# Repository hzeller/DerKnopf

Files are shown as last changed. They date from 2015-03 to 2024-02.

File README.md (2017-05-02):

Remote controlled volume knob
=============================

_**Knopf, der** German: button, knob (Pronounciation: /knɔpf/)_

A project to upgrade an amplifier volume knob from a simple regular
potentiometer to a digital one that still can be controlled
directly at the amplifier but also via an infrared remote control.

Replaces the regular potentiometer with a [DS1882] and a rotational encoder.
Visual feedback with a charlie-plexed LED ring.

The interesting part is the infrared remote control: another rotational encoder,
with an infrared transmitter: a wireless extension of the volume knob.

The rotational encoders have a secondary push-button function which is used to
enable muting. Another press on that button will un-mute and go back to the
original volume.

# Remote control sender
The [sender](./pcb/remote-control) is a 20mm round PCB and thus roughly the
size of the volume knob and the diameter of a CR2032 battery.

Provides a rotational encoder with an integrated button (used for 'mute'), two
Infrared LEDs to send.
Microcontroller: Attiny44. Quiescent current: < 0.2 μA. Runs on CR2032.

Top                    | Side                       | Bottom
-----------------------|----------------------------|--------------------------
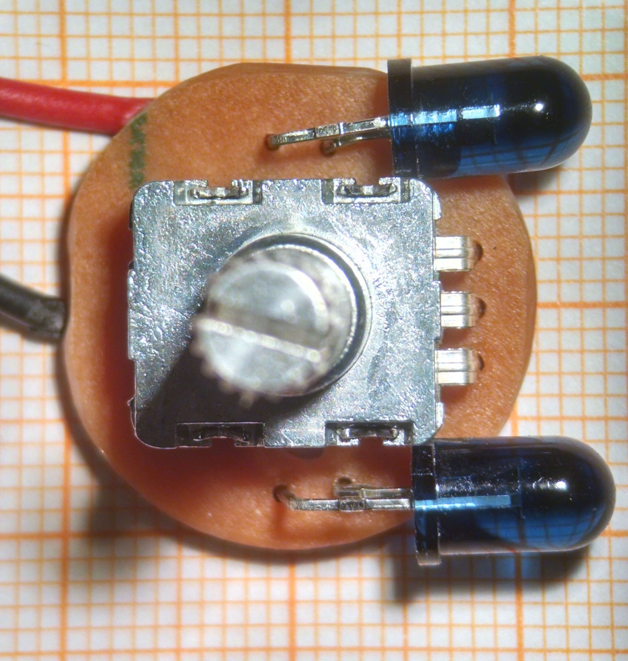
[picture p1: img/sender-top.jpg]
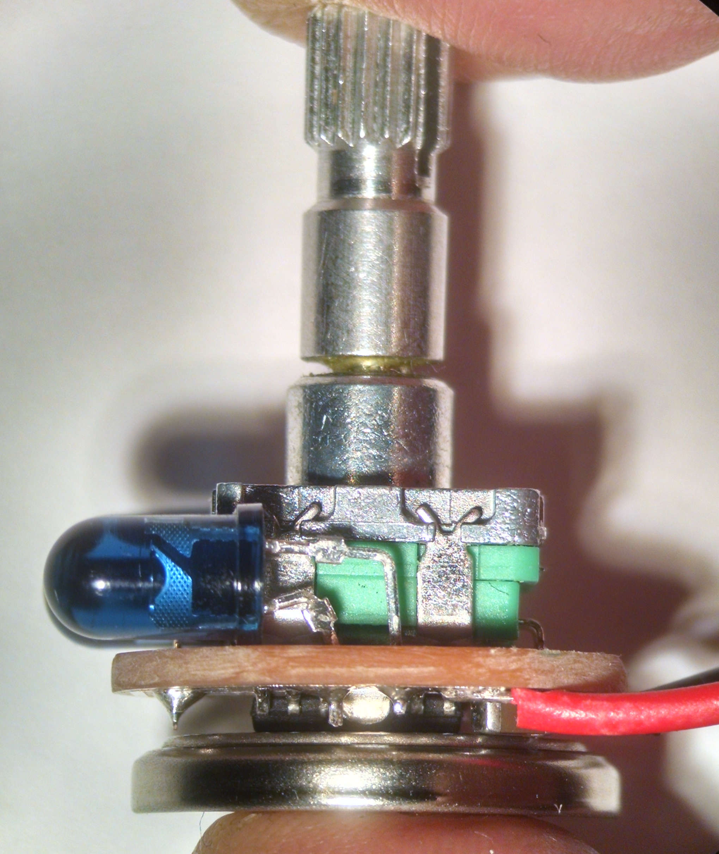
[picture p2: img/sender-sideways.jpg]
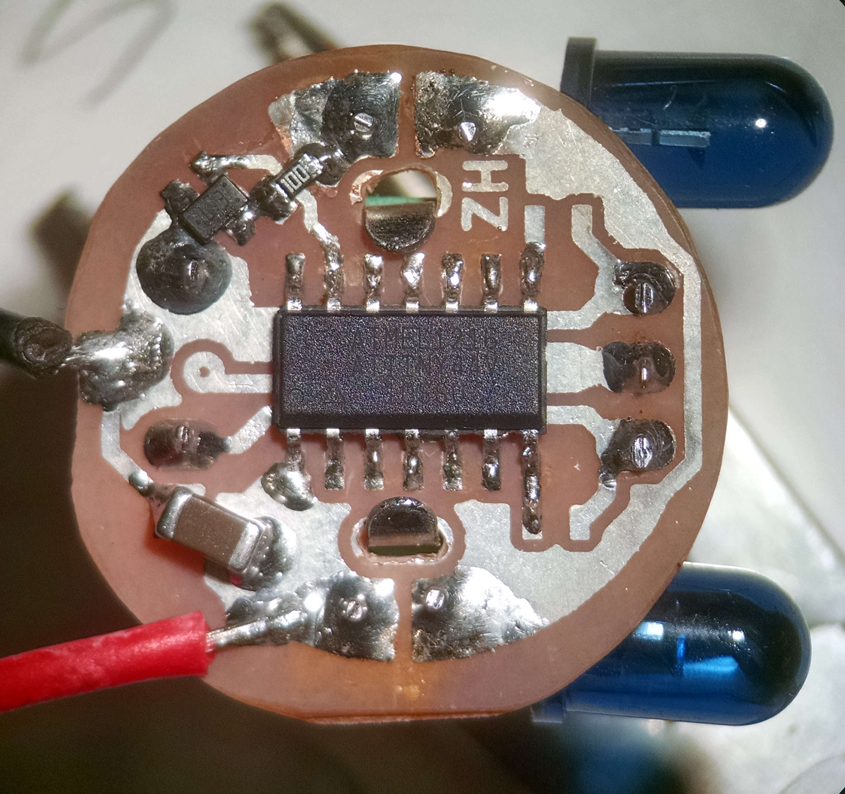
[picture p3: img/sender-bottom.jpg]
||

TODO: build acryilic housing.

Code in [sender/](./sender) directory.

# DigiPot Receiver

The [receiver](pcb/digi-pot) behaves like a logarithmic stereo potentiomter.
It takes an input signal from a local rotational encoder or the infrared
signal (amplified and prepared with a Vishay TSOP75338).
It provides two 'potentiometer' outputs. The local encoder has a 32 step/turn
resolution of which 30 are used (to have a visual 'gap' between min and max
like in a regular pot).

Microcontroller: Attiny48.
Runs on +5V (digital processing) and +/-6V (Analog). For these voltge rails,
there is a little separate [power supply PCB](./pcb/power)

Code in [receiver/](./receiver) directory.

Render                      |  Bottom                      | Shallow side view
----------------------------|------------------------------|----------------------------|
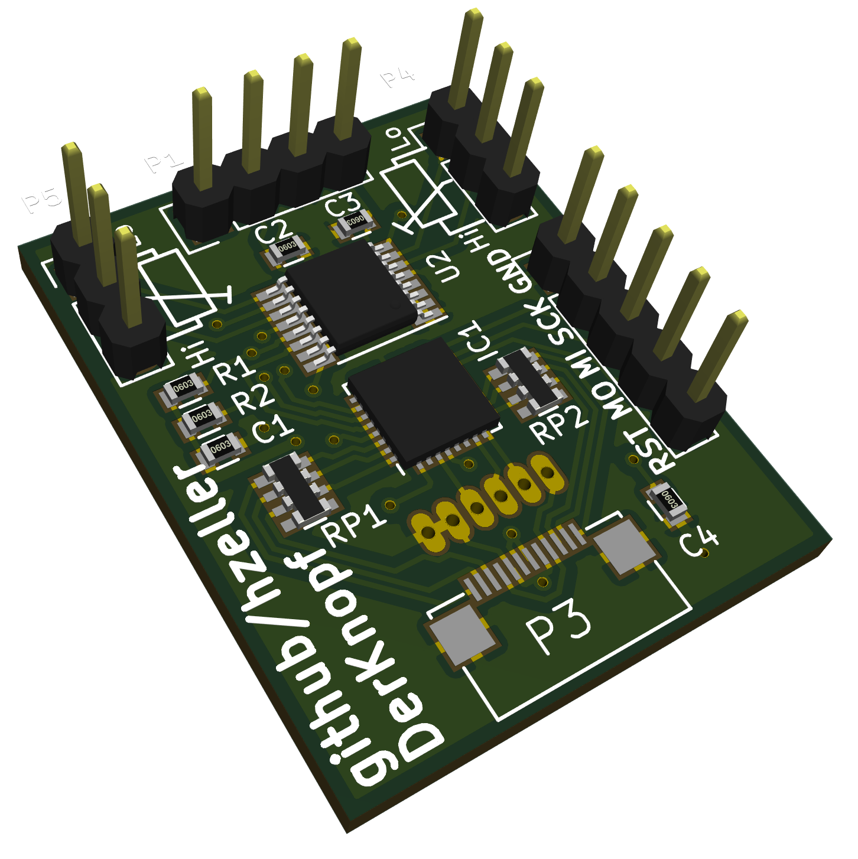
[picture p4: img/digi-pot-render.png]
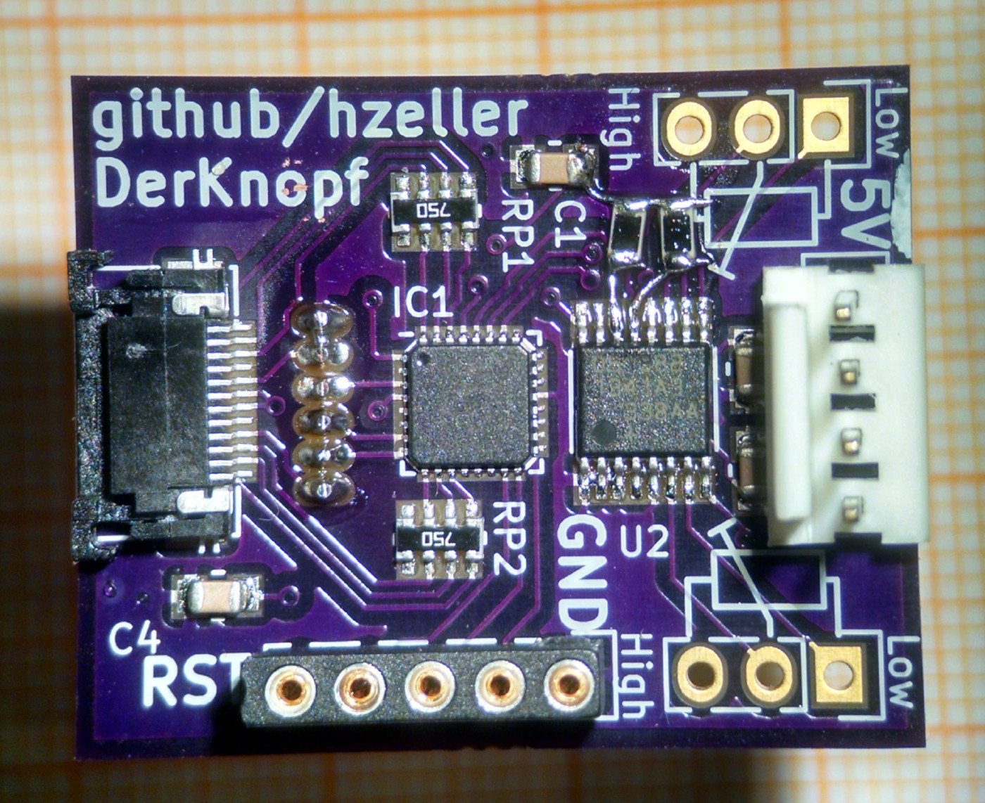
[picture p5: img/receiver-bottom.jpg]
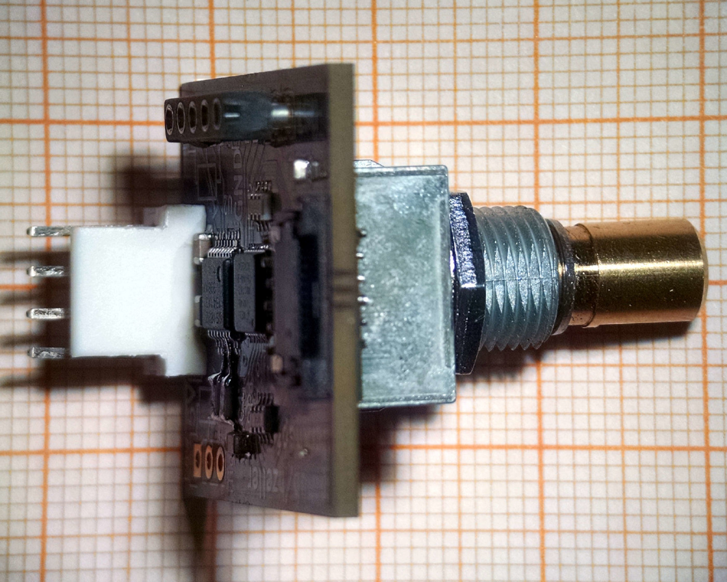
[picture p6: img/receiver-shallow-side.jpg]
| (This early revision required some bodge resistors)||

# LED Ring
The [LED ring](./pcb/led-ring) is mounted on the front-panel of the amplifier
around the volume knob. In this case, this is a 19mm knob, so the ring is 20mm.

It contains 30 charlie-plexed LEDs to display the current 'position' and the
TSOP IR module. On mute, the current volume position is blinking (controlled by
the [DigiPot](./pcb/digi-pot)).

The round board connects with the main receiver board via a 12 connect,
0.5mm pitch flat flex cable.

Render                       | Real
-----------------------------|----------------------
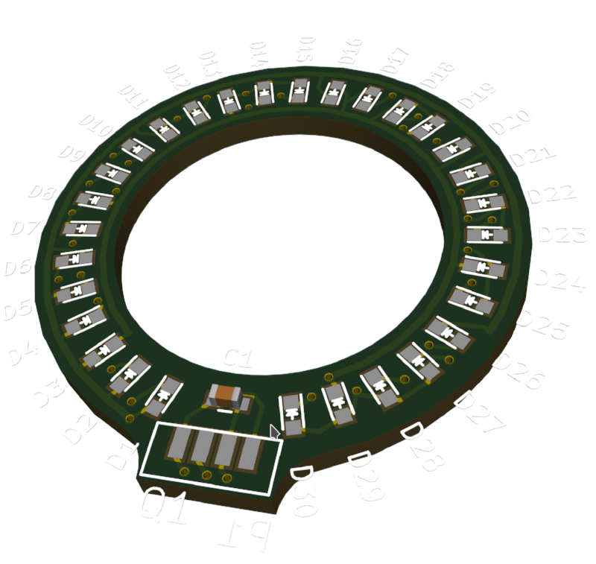
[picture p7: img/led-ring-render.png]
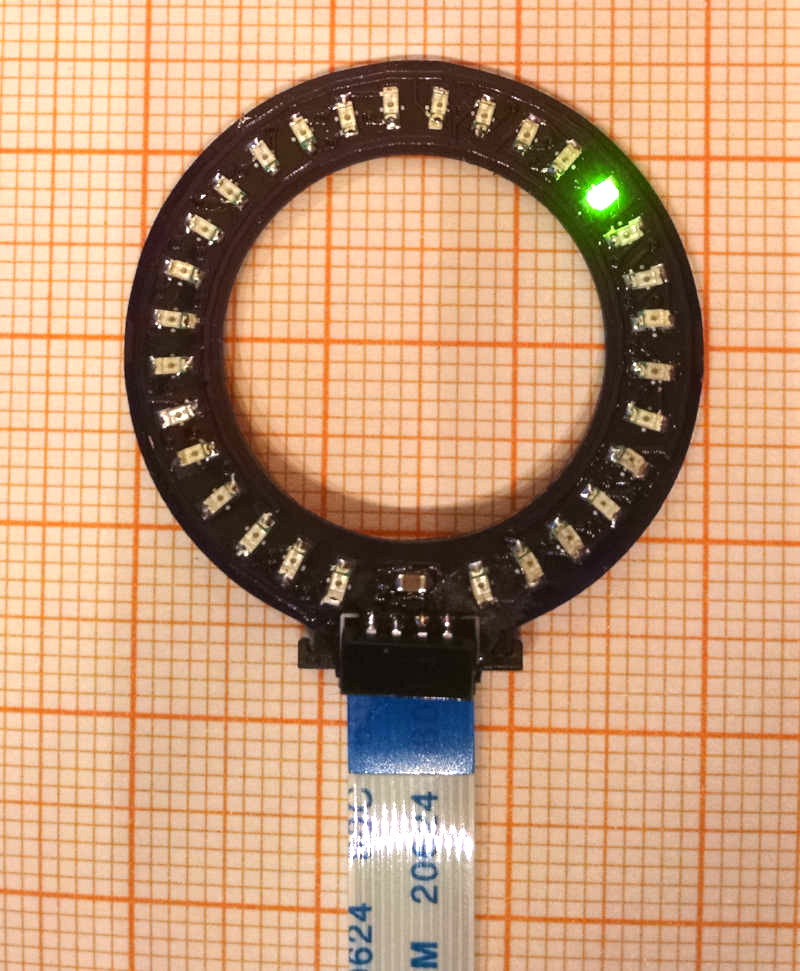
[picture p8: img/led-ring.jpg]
 | 

### Mounted on Amplifier and final Remote Control

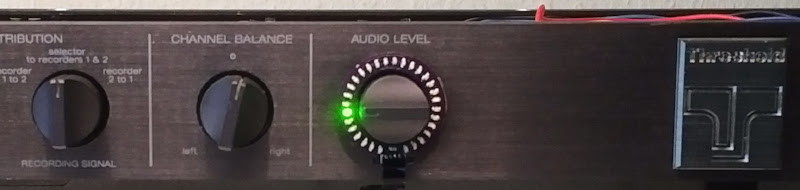
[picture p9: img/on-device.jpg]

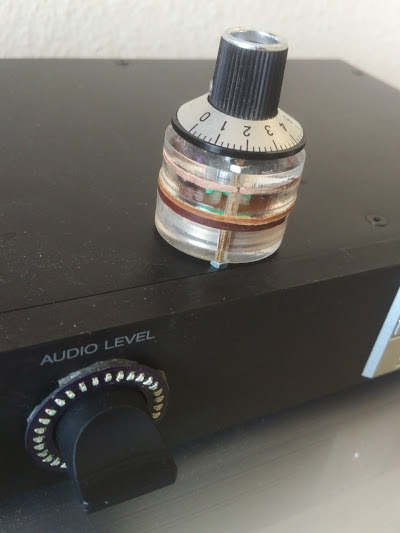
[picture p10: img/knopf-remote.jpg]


[DS1882]: https://datasheets.maximintegrated.com/en/ds/DS1882.pdf

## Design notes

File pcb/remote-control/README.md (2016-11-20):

Remote Control
==============

The remote control, operated with an Attiny44 on a CR2032 battery. Processor
gets woken up from power down state on state change of the inputs, so quiescent
current is less than 0.2 μA.

It is not clear yet if the CR2032 increase in internal resistance over time will
be sufficient for our desired peak-current of 120mA through the IR LEDs (only
partially on, so average current ~40mA). So future revisions might consider
adding some electrolytic capacitors (but we'd need > 4700uF to power one
transmit of about 64ms * 40mA * 3V ~= 8mJ), or changing the battery (CR2450 or
even two AAA or AAAA).

With optional 1M pullups for the mechanical encoder, as these sometimes get
stuck in some half position, draining current through the pull-ups. The
standard pullups inside the attiny are aorund 60k (Note: this feature is not
used in the assembly below, just using the internal resistors.)

The programming header shown in the schematic does not have a component
associated on the board as it was too bulky.

Single-sided board for simple home-etching.

## BOM
  * 1x rotational encoder with push-button (here: EN11-HSB1AQ20, but might consider EN11-HSM1AF15 in the future for better mounting. See [EN11-datasheet])
  * 1x Attiny44
  * 1x 22μF ceramic capacitor (1206)
  * 1x 100n ceramic capacitor (0603)
  * 2x 1M resistor (0603)
  * 1x 4.7Ohm resistor (0805)
  * 1x MTM232270 N-channel Mosfet (SOT-323)

Top                    | Side                       | Bottom
-----------------------|----------------------------|--------------------------
||

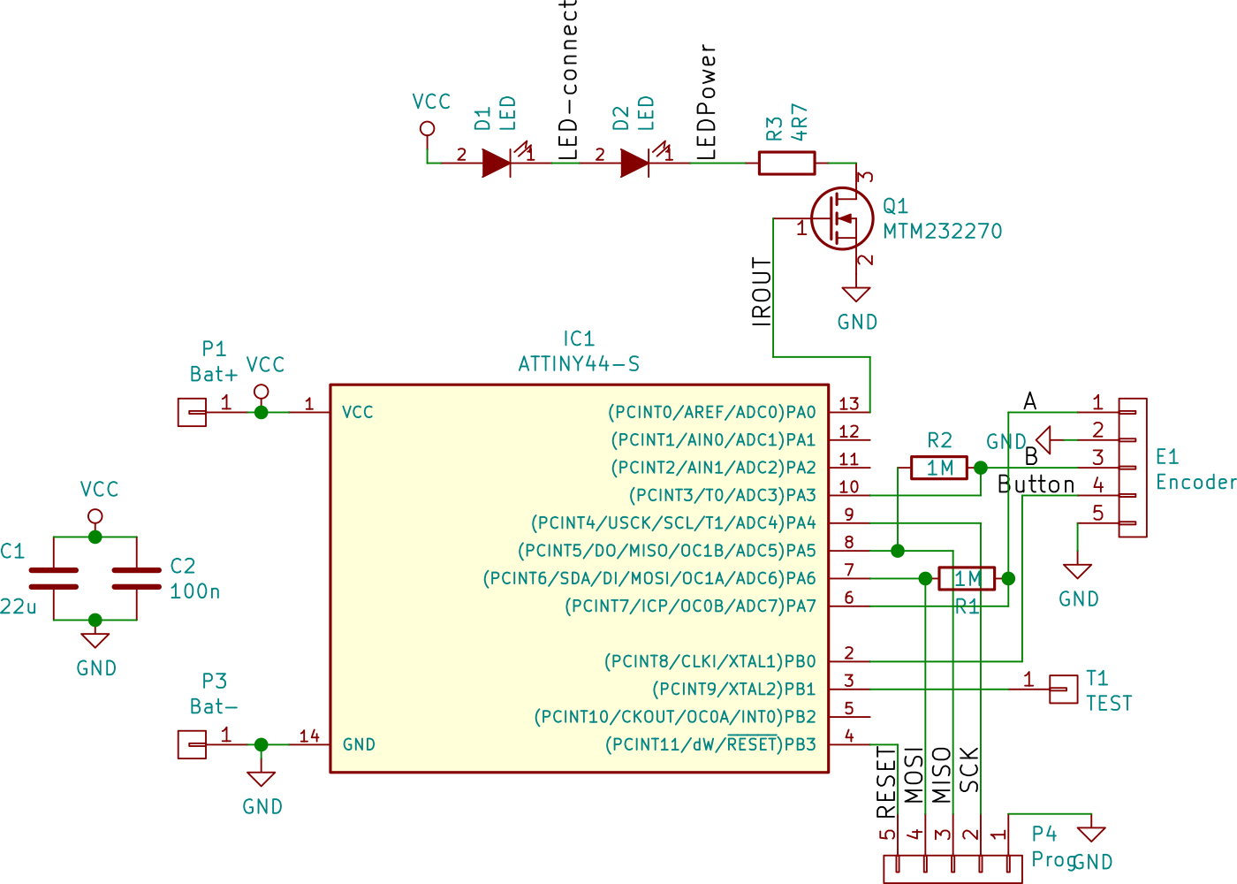
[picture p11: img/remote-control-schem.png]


[EN11-datasheet]: http://www.bitechnologies.com/pdfs/en11.pdf

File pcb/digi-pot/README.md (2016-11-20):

DigiPot
=======

The actual simulated pot with connectors for the LED ring, the IR receiver and
a local optical rotational encoder to have the feel of a local potentiometer.

This encoder replaces an existing high-quality ALPS potentiometer with 30 detents.
It is surprisingly hard to find a mechanical encoder with the same solid feel
and 32 detents (most mechanical enoders only go to 20 steps/turn).

The CUI optical encoder is perfect for this job but about as expensive as the
potentiometer it replaces.

## BOM

 * 2x 4.7k 0603 resistor
 * 4x 100n 0603 capacitor
 * 2x (4x75 Ohm) resistor network.
 * 1x Attiny48
 * 1x DS1882
 * 1x CUI C14D32P-A3 optical encoder.
 * 1x FlatFlex 12Pin connector.

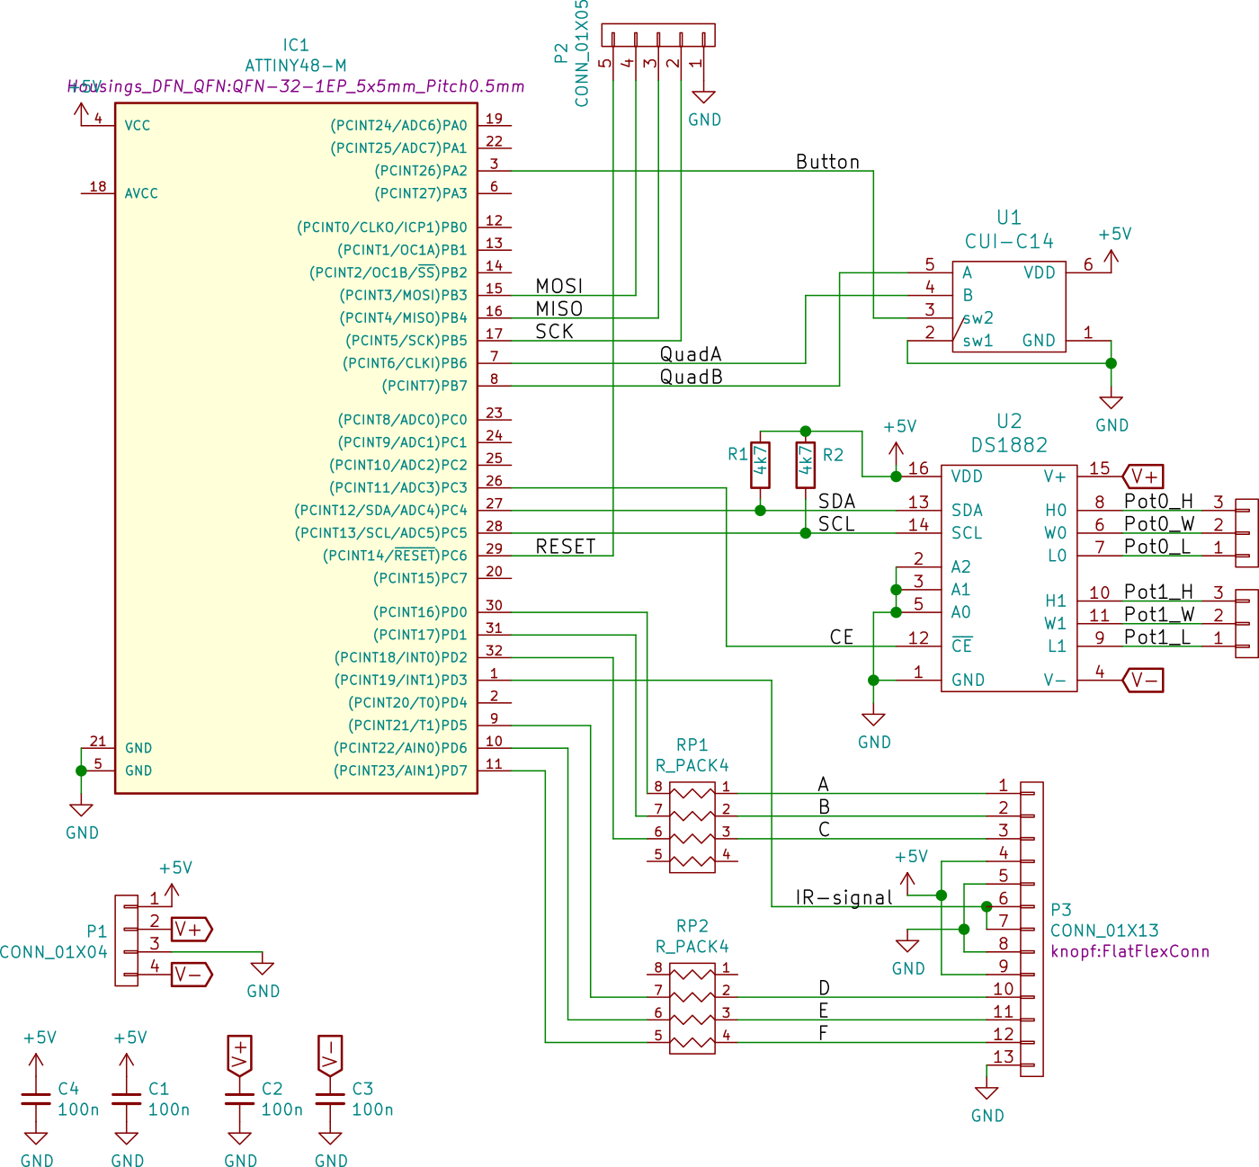
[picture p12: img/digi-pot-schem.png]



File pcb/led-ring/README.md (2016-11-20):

Led-Ring
========

Led-ring with 30 charlie-plexed LEDs to display the position of the pot.
Also, since this is mounted on the front-panel, the place for the IR receiver.

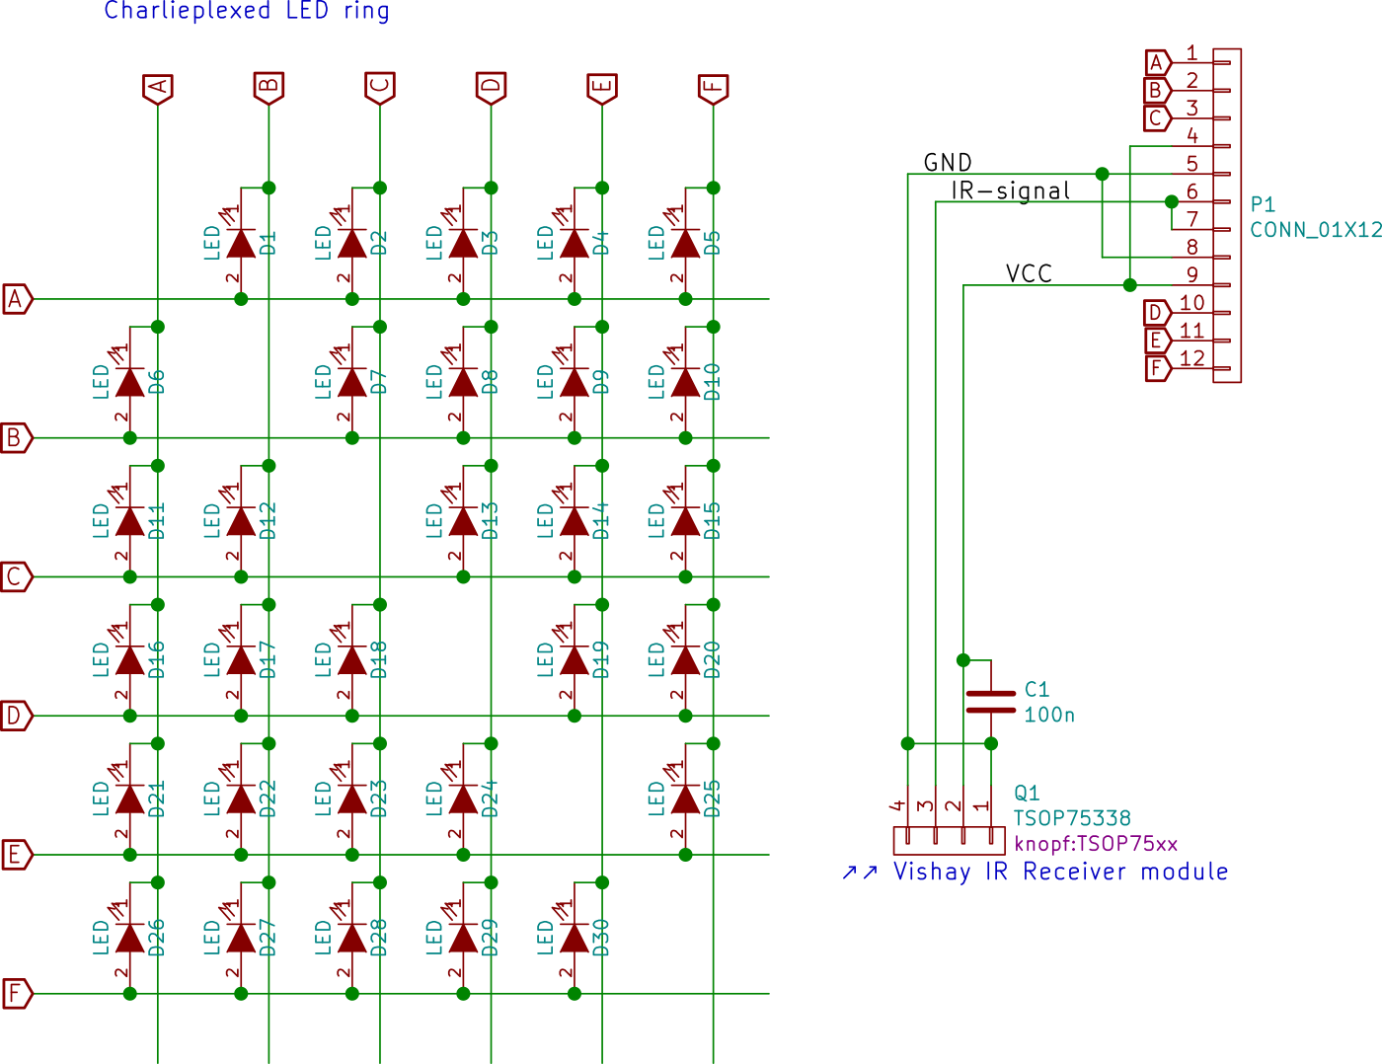
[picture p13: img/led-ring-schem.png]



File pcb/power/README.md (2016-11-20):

Power supply
============

The DigiPot needs 5V for digital operation and +/- 6V for the analog part.
Assuming that we already have some symmetric power in the amplifier, this
creates the necessary voltages. The current demands on the analog rails are
miniscule, so small SOT89-3 are sufficient for the task.

The 5V rail needs something in the 30mA range (operate microcontroller,
LEDs on LED ring and optical encoder), so depending on the input
voltage that could be some noticeable generated heat, hence we use a TO220 case.

Single sided board for simple home-etching.

## BOM

 * 1x 78L06 SOT89-3
 * 1x 79L06 SOT89-3
 * 1x 7805 TO220
 * 3x 100n capacitor, 0805
 * 2x 10uF ceramic capacitor, 50V, 1206

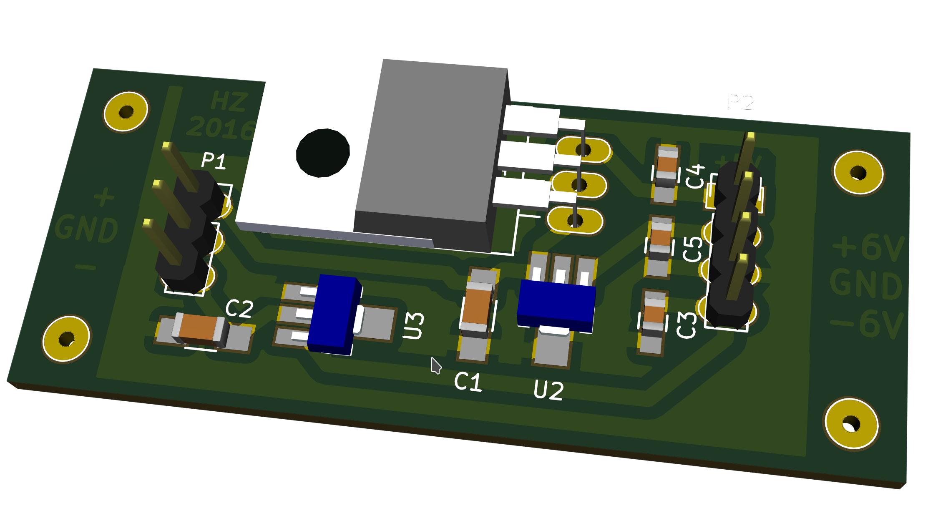
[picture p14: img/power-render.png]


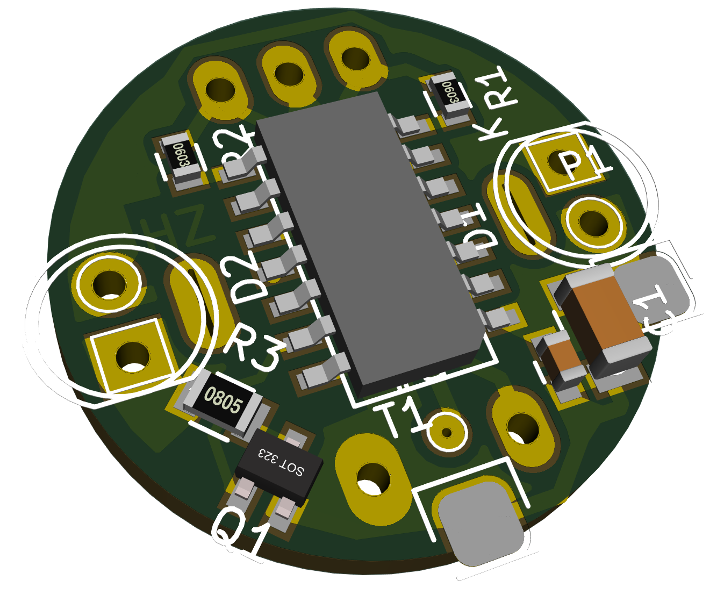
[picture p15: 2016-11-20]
img/remote-control-render.png

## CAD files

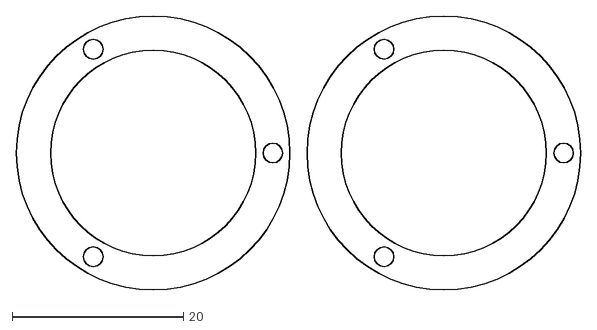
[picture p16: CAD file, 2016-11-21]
hardware/remote.dxf
66.0 x 32.0

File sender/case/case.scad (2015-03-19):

include <knob.scad>

$fn=180;
epsilon=0.02;
clearance = 0.35;
pcb_width=14;
pcb_distance=1;
diameter=65;   // TODO: calculate.
batt_len=44.5 + 6 + 2*clearance;  // Additional space for contacts
batt_dia=10.5 + 2*clearance;
batt_blade_thick=1.5;
font="Helvetica:style=Bold";
total_height=28;
vertical_divide=15;
knob_overlap=6;
bottom_thick=3.2;  // acrylic is about 3.4mm thick
led_mount_dia=6.4;
case_knob_clearance=0.5;

module led(dia=5.3) {
    // Nice infrared purple :)
    color("purple") {
	sphere(r=dia/2);
	cylinder(r=dia/2,h=8.5 - dia/2);
	translate([0,0,8.5-dia/2-2]) cylinder(r=dia/2 + 0.5, h=2);
    }
}

module battery(length=batt_len, dia=batt_dia,negatives=true) {
    translate([-batt_len/2,0,0]) {
	translate([0,0,dia/2]) rotate([0,90,0]) cylinder(r=dia/2, h=length);
	translate([0,-dia/2,0]) cube([length, dia, dia/2]);
	if (negatives) {
	    // Contact blades
	    translate([0,-0.6*dia,-1]) cube([batt_blade_thick, 30, dia+1]);
	    translate([batt_len-1,-0.6*dia,-1]) cube([batt_blade_thick, 1.4*dia,dia+1]);

	    // +/- text
	    translate([0,0,dia/2]) rotate([0,0,0]) union(){
		translate([10,-6/2,0]) color("black") linear_extrude(height=dia/2 + 0.6) text("–", size=8, font=font);
		translate([length-15,-6/2,0]) color("red") linear_extrude(height=dia/2 + 0.6) text("+", size=8, font=font);
	    }
	}
    }
}

module m3_bolt(h=2.6) {
    cylinder(r=6.4/2, h=h, $fn=6);
}

module remote_control(l=37, w=pcb_width, h=9,negatives=true) {
    translate([-l/2,-w/2,0]) cube([l,w,h]);
    if (negatives) color("lightblue") {
	difference() {    // turn shaft
	    cylinder(r=6.4/2, h=h + 14.55 + 0.5/*fudge*/);
	    // ... with flattened side.
	    translate([-4, 1.6, -epsilon]) cube([8, 8, 25+2*epsilon]);
	}
	cylinder(r=9/2 + clearance, h=h + 6.8);  // mount shaft

	// set screw
	translate([0,0,h + 10]) rotate([-90, 0, 0]) union() {
	    cylinder(r=3.2/2, h=50);
	    translate([0,0,3]) {
		// Space for bolt
		rotate([0,0,30]) m3_bolt();
		translate([-5.5/2,0,0]) cube([5.5, 6, 2.6]);
	    }
	    translate([0,0,9.5]) {
		// Space to drop screw in.
		cylinder(r=6/2, h=12);
		translate([0,0,12-4]) translate([-6/2,0,0]) cube([6, 7, 4]);
		translate([-3/2,0,0]) cube([3, 7, 12]);
	    }
	}

	// Mounting gear on encoder
	translate([0,0,h + 2.9]) cylinder(r=16/2 + clearance, h=3.5);
	// Retainer clip for encoder
	translate([6, -3/2, 0]) cube([2, 3, h+3]);
    }

    if (negatives) {
	// Infrared diodes
	// Mounting holes
	translate([0,0,led_mount_dia/2-2]) {
	    rotate([0,90,0]) translate([0,0,-30]) cylinder(r=led_mount_dia/2, h=60);
	    // LEDs
	    translate([-knob_dia/2+2,0,0]) rotate([0,90,0]) led();
	    translate([knob_dia/2-2,0,0]) rotate([0,-90,0]) led();
	}
    }
}

module two_batt_module(negatives=true) {
    translate([-batt_len/2,0,0]) {
	translate([batt_len/2,-(batt_dia+pcb_width)/2-pcb_distance,0]) battery(negatives=negatives);
	translate([batt_len/2,+(batt_dia+pcb_width)/2+pcb_distance,0]) rotate([0,0,180]) battery(negatives=negatives);
    }
}

module three_batt_module() {
    difference() {
	cylinder(r=70/2, h=15);
	translate([-22,-20,-epsilon]) {
	    battery();
	    translate([batt_len + 7, 10,0]) rotate([0,0,120]) battery();
	    translate([- 7, 10,0]) rotate([0,0,60]) battery();
	}
    }
}

module item_blocks(negatives=true, offset=0) {
    two_batt_module(negatives=negatives);
    remote_control(negatives=negatives);
}

module bottom(h=bottom_thick, larger=0, fudge=1.246, negatives=false) {
    echo("Bottom diameter", (diameter - 0)/2 - larger);
    //translate([0,0,-3]) color("red") cylinder(r=31.511, h=h);
    // Fudge factor - for some reason, the dxf is completely non-scaled.
    minkowski() {
	rotate([0,0,90]) linear_extrude(height=h) scale(31.511/fudge) translate([-fudge,-fudge]) import(file = "bottom.dxf");
	cylinder(r=larger, h=epsilon);
    }
    if (negatives) {
	// Drill holes through the case
	translate([0, 25, 0]) {
	    cylinder(r=3.4/2, h=20);
	    translate([0,0,10]) m3_bolt(h=12);
	}
	translate([0, -25, 0]) {
	    cylinder(r=3.4/2, h=20);
	    translate([0,0,10]) m3_bolt(h=12);
	}
    }
}

module case(base_high=vertical_divide, bottom_thick=bottom_thick) {
    difference() {
	union() {
	    cylinder(r=diameter/2 - clearance, h=base_high);
	    knurls(h=base_high-knob_overlap-case_knob_clearance);
	}
	translate([0,0,-epsilon]) {
	    translate([0,0,bottom_thick - epsilon]) {
		two_batt_module(negatives=true);
		remote_control(negatives=true);
	    }
 	    bottom(h=bottom_thick, larger=clearance, negatives=true);
	}
    }
}

module knob(hovering=vertical_divide, inner_clearance=2, bottom_thick=bottom_thick) {
    translate([0, 0, hovering - knob_overlap]) difference() {
	// Full knob...
	knurl_knob(total_height - hovering + knob_overlap);

	// Minus interior
	translate([0,0,-epsilon]) cylinder(r=diameter/2 + clearance, h=knob_overlap + inner_clearance);
	translate([0,0,bottom_thick-hovering+knob_overlap]) item_blocks(negatives=true);
    }
}

module xray() {
    difference() {
	union() {
	    case(base_high=vertical_divide);
	    color("red") knob(hovering=vertical_divide);
	    %bottom();
	}
	translate([0,0,-epsilon]) cube([100,100,100]);
    }
}

//bottom(negatives=true);
//battery();
//xray();
//led();
//knob();
//case();
//rotate([180, 0, 0]) knob();
rotate([180,0,0]) case();
//sphere(r=10, $fn=8);
//translate([0,0,bottom_thick]) remote_control();
//translate([-40,0,0]) two_batt_module();
//translate([+40,0,0]) three_batt_module();
//rotate([0,0,90]) m3_bolt();
//translate([0,7,0]) cube([5.4, 10, 1], center=true);

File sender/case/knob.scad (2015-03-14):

$fs=0.2;
$fa=1;

knob_dia=71;
knob_height=19;
knob_cut_angle=46.5;
knob_knurl_depth=2;
knob_dividers=12;  // Should be the number of detents in rotatry encoder
knob_top_roundness=5;

module base_knob(h=knob_height) {
    hull() {
	cylinder(r=knob_dia/2,h=1);
	translate([0,0,h - knob_top_roundness])
	   rotate_extrude(convexity=10) translate([knob_dia/2 - knob_top_roundness,0,0]) circle(r=knob_top_roundness);
    }
}

function polar_x(r, angle) = r * cos(angle);
function polar_y(r, angle) = r * sin(angle);
function knurl(fraction, knurl_dia=knob_knurl_depth/2) = sin(fraction * 360) * knurl_dia - knurl_dia;

module knob_slice(r=knob_dia/2,segments=knob_dividers) {
    a = 360 / knob_dividers / 15;
    poly = [[0,0],
	[polar_x(r + knurl(0),   0*0), polar_y(r + knurl(0),0*a)],
	[polar_x(r + knurl(1/15),1*a), polar_y(r + knurl(1/15),1*a)],
	[polar_x(r + knurl(2/15),2*a), polar_y(r + knurl(2/15),2*a)],
	[polar_x(r + knurl(3/15),3*a), polar_y(r + knurl(3/15),3*a)],
	[polar_x(r + knurl(4/15),4*a), polar_y(r + knurl(4/15),4*a)],
	[polar_x(r + knurl(5/15),5*a), polar_y(r + knurl(5/15),5*a)],
	[polar_x(r + knurl(6/15),6*a), polar_y(r + knurl(6/15),6*a)],
	[polar_x(r + knurl(7/15),7*a), polar_y(r + knurl(7/15),7*a)],
	[polar_x(r + knurl(8/15),8*a), polar_y(r + knurl(8/15),8*a)],
	[polar_x(r + knurl(9/15),9*a), polar_y(r + knurl(9/15),9*a)],
	[polar_x(r + knurl(10/15),10*a), polar_y(r + knurl(10/15),10*a)],
	[polar_x(r + knurl(11/15),11*a), polar_y(r + knurl(11/15),11*a)],
	[polar_x(r + knurl(12/15),12*a), polar_y(r + knurl(12/15),12*a)],
	[polar_x(r + knurl(13/15),13*a), polar_y(r + knurl(13/15),13*a)],
	[polar_x(r + knurl(14/15),14*a), polar_y(r + knurl(14/15),14*a)],
	[polar_x(r + knurl(15/15),15*a), polar_y(r + knurl(15/15),15*a)],
	// Add a little bit of overlap to the next slice:
	[polar_x(r + knurl(16/15),16*a), polar_y(r + knurl(16/15),16*a)],
        [0,0]];
    polygon(points=poly, convexity=2);
}

module knurls(h=knob_height, angle_offset=90 / knob_dividers) {
    linear_extrude(height=h) for (i=[0:360/knob_dividers:359]) {
	rotate([0,0,i+angle_offset]) knob_slice();
    }
}

module knurl_knob(h=knob_height) {
    intersection() {
	knurls(h);
	base_knob(h);
    }
}

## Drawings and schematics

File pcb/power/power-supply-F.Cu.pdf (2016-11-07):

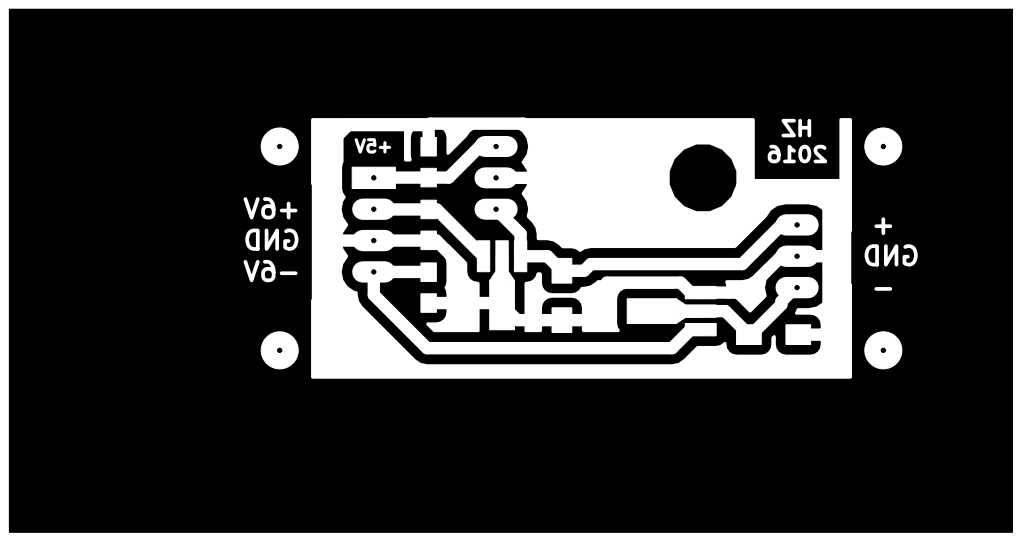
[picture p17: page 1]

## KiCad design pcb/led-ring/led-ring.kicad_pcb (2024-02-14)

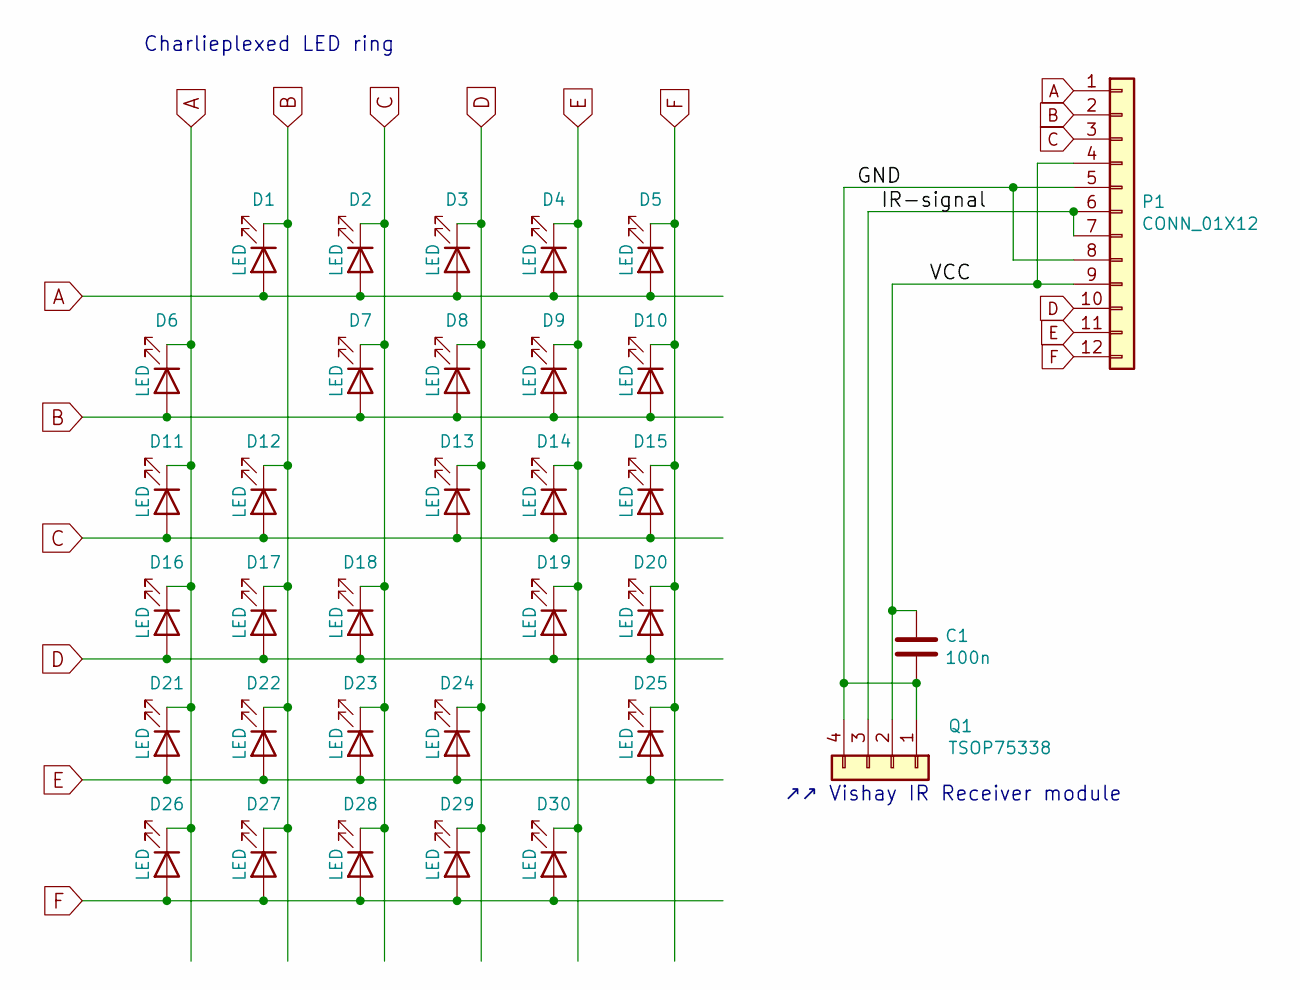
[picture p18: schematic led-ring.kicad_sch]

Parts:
C1: 100n; C_0603_1608Metric
D1, D2, D3, D4, D5, D6, D7, D8, D9, D10, D11, D12, D13, D14, D15, D16, D17, D18, D19, D20, D21, D22, D23, D24, D25, D26, D27, D28, D29, D30: LED; LED_0603_1608Metric
P1: CONN_01X12; FlatFlex
Q1: TSOP75338; TSOP75xx

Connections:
/GND: C1.2, P1.5, P1.8, Q1.1, Q1.4
/IR-signal: P1.6, P1.7, Q1.3
/VCC: C1.1, P1.4, P1.9, Q1.2
A: D1.2 (A), D2.2 (A), D3.2 (A), D4.2 (A), D5.2 (A), D6.1 (K), D11.1 (K), D16.1 (K), D21.1 (K), D26.1 (K), P1.1
B: D1.1 (K), D6.2 (A), D7.2 (A), D8.2 (A), D9.2 (A), D10.2 (A), D12.1 (K), D17.1 (K), D22.1 (K), D27.1 (K), P1.2
C: D2.1 (K), D7.1 (K), D11.2 (A), D12.2 (A), D13.2 (A), D14.2 (A), D15.2 (A), D18.1 (K), D23.1 (K), D28.1 (K), P1.3
D: D3.1 (K), D8.1 (K), D13.1 (K), D16.2 (A), D17.2 (A), D18.2 (A), D19.2 (A), D20.2 (A), D24.1 (K), D29.1 (K), P1.10
E: D4.1 (K), D9.1 (K), D14.1 (K), D19.1 (K), D21.2 (A), D22.2 (A), D23.2 (A), D24.2 (A), D25.2 (A), D30.1 (K), P1.11
F: D5.1 (K), D10.1 (K), D15.1 (K), D20.1 (K), D25.1 (K), D26.2 (A), D27.2 (A), D28.2 (A), D29.2 (A), D30.2 (A), P1.12

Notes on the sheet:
↗↗ Vishay IR Receiver module
Charlieplexed LED ring

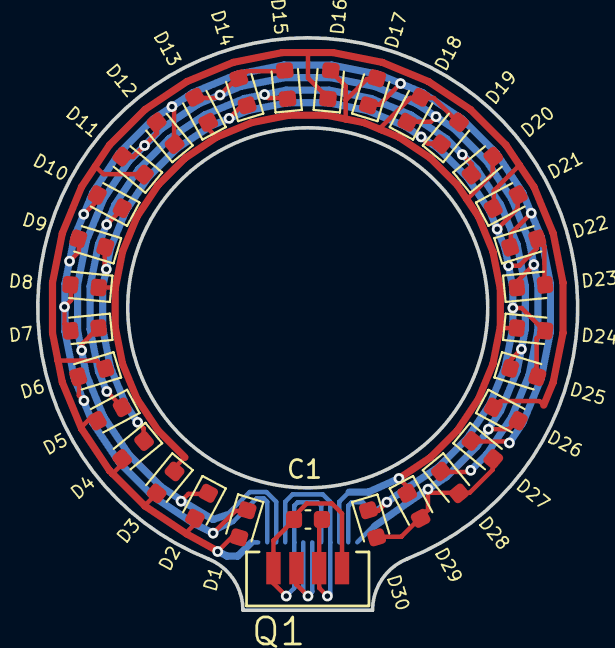
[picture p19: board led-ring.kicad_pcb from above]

Board: 2 copper layers, 30.0 x 31.8 mm, 33 parts (1 on the bottom side), 9 nets.

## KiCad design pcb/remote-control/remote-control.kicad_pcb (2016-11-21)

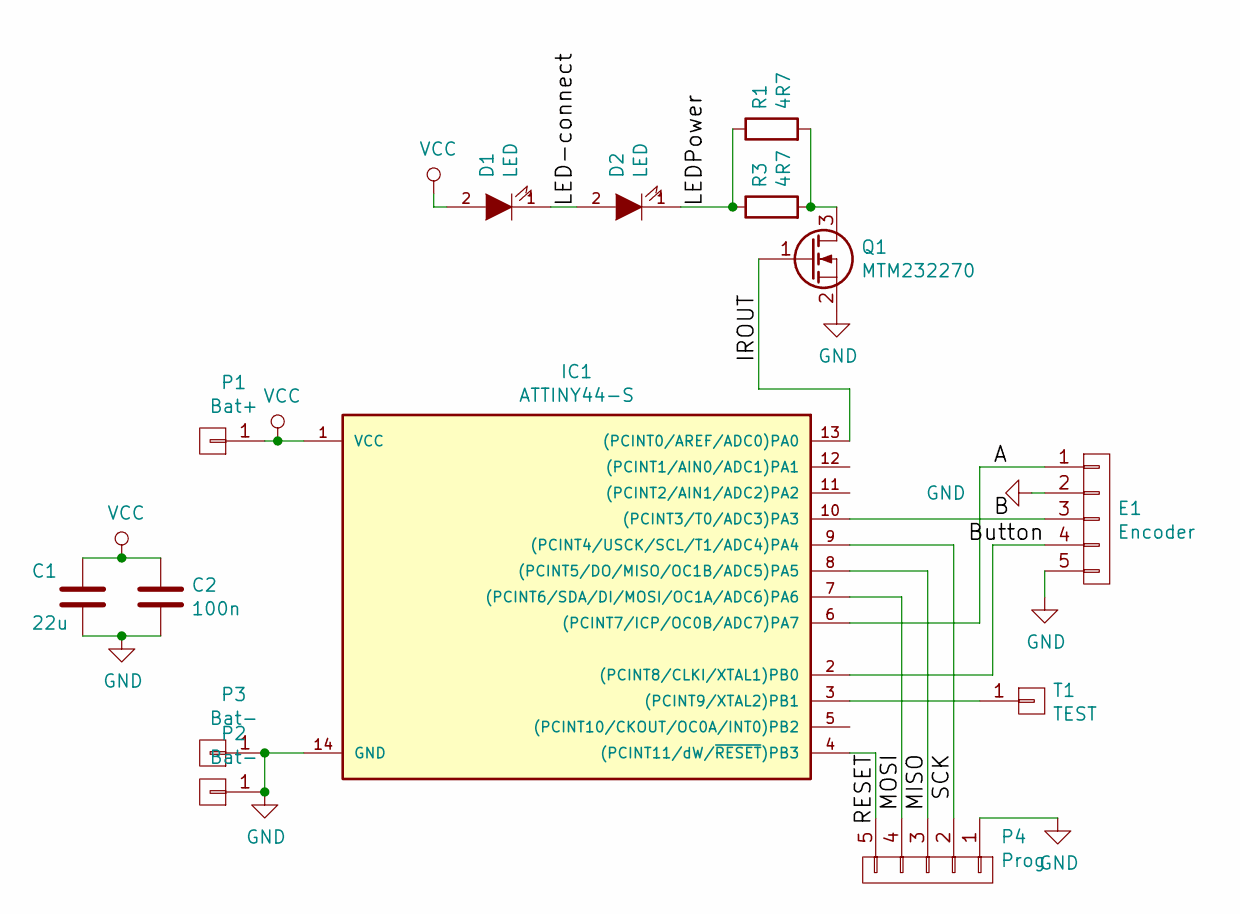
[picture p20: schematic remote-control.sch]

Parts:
C1: 22u; C_1206
C2: 100n; C_0603
D1, D2: LED; LED-5MM
E1: Encoder; MechanicalEncoder
IC1: ATTINY44-S; SOIC-14_N
P1: Bat+; Pin_Header_Straight_1x01
P2, P3: Bat-; Pin_Header_Straight_1x01
P4: Prog
Q1: MTM232270; SOT-323
R1, R3: 4R7; R_0805
T1: TEST; TestPoint

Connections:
/A: E1.1, IC1.6 ((PCINT7/ICP/OC0B/ADC7)PA7)
/B: E1.3, IC1.10 ((PCINT3/T0/ADC3)PA3)
/Button: E1.4, IC1.2 ((PCINT8/CLKI/XTAL1)PB0)
/IROUT: IC1.13 ((PCINT0/AREF/ADC0)PA0), Q1.1 (G)
/LED-connect: D1.1 (K), D2.2 (A)
/LEDPower: D2.1 (K), R1.1, R3.1
/MISO: IC1.8 ((PCINT5/DO/MISO/OC1B/ADC5)PA5), P4.3
/MOSI: IC1.7 ((PCINT6/SDA/DI/MOSI/OC1A/ADC6)PA6), P4.4
/RESET: IC1.4 ((PCINT11/dW/~RESET~)PB3), P4.5
/SCK: IC1.9 ((PCINT4/USCK/SCL/T1/ADC4)PA4), P4.2
GND: C1.2, C2.2, E1.2, E1.5, IC1.14 (GND), P2.1, P3.1, P4.1, Q1.2 (S)
unnamed: IC1.3 ((PCINT9/XTAL2)PB1), T1.1
unnamed: Q1.3 (D), R1.2, R3.2
VCC: C1.1, C2.1, D1.2 (A), IC1.1 (VCC), P1.1

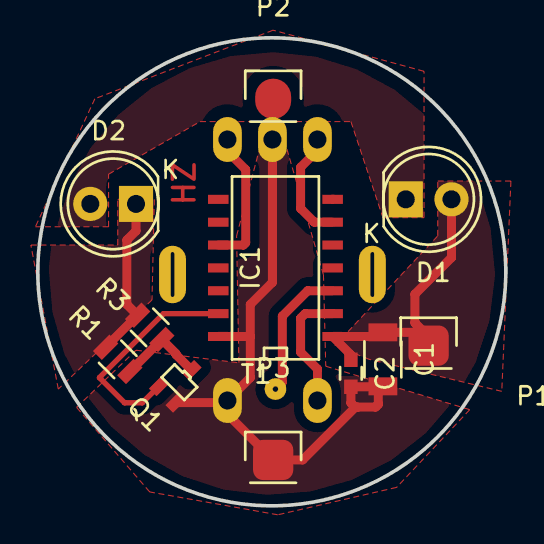
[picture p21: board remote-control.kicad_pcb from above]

Board: 2 copper layers, 26.0 x 26.0 mm, 13 parts (1 on the bottom side), 10 nets.

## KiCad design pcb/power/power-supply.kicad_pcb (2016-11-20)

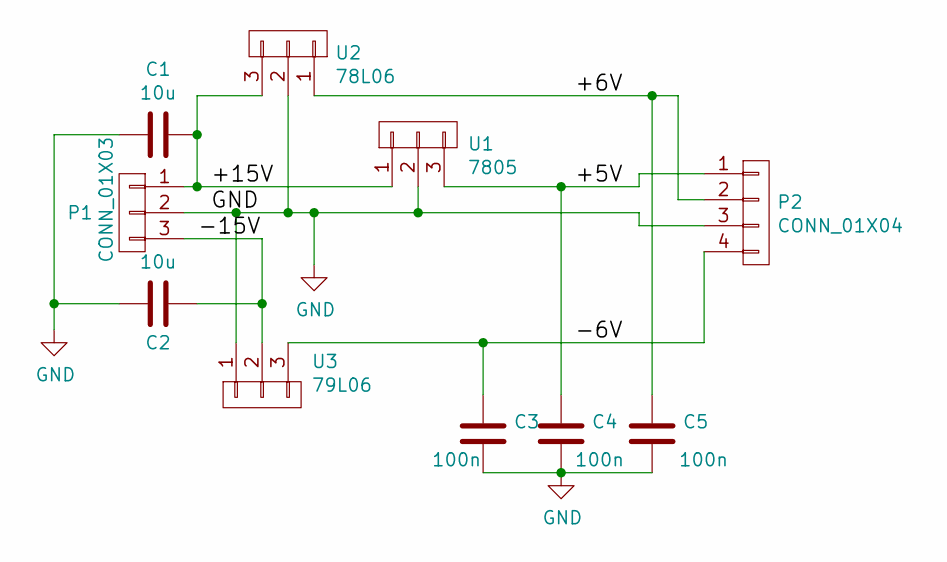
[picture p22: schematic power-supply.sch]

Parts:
C1, C2: 10u; C_1206_HandSoldering
C3, C4, C5: 100n; C_0805_HandSoldering
P1: CONN_01X03; Pin_Header_Straight_1x03
P2: CONN_01X04; Pin_Header_Straight_1x04
U1: 7805; TO-220_Neutral123_Horizontal_LargePads
U2: 78L06; SOT89-3_Housing_Handsoldering
U3: 79L06; SOT89-3_Housing_Handsoldering

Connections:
/+5V: C4.1, P2.1, U1.3
/+6V: C5.1, P2.2, U2.1
/+15V: C1.1, P1.1, U1.1, U2.3
/-6V: C3.1, P2.4, U3.3
/-15V: C2.1, P1.3, U3.2
GND: C1.2, C2.2, C3.2, C4.2, C5.2, P1.2, P2.3, U1.2, U2.2, U3.1

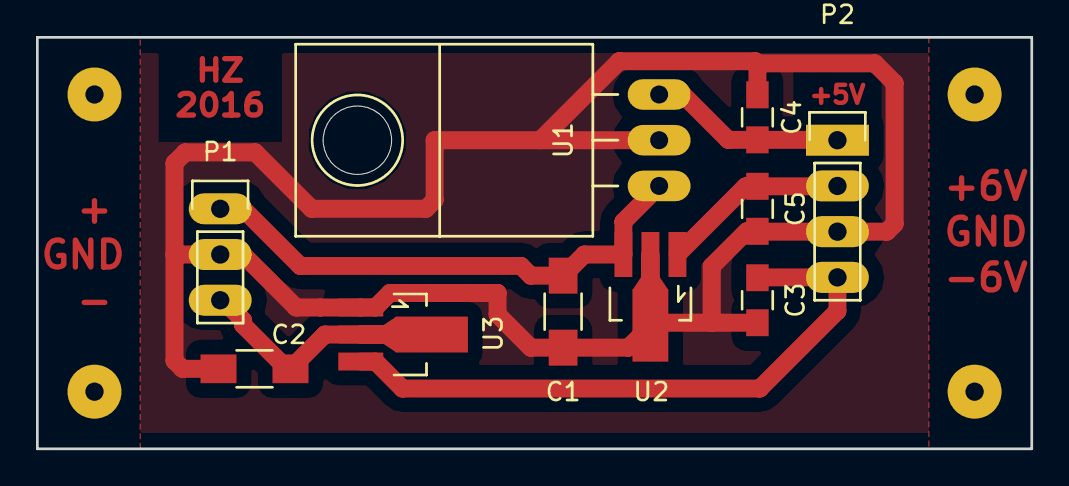
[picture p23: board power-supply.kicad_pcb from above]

Board: 2 copper layers, 55.2 x 22.9 mm, 14 parts (0 on the bottom side), 6 nets.

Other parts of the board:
R: D; Pin_Header_Straight_1x01
R#2, R#3, R#4: D; Pin_Header_Straight_1x01

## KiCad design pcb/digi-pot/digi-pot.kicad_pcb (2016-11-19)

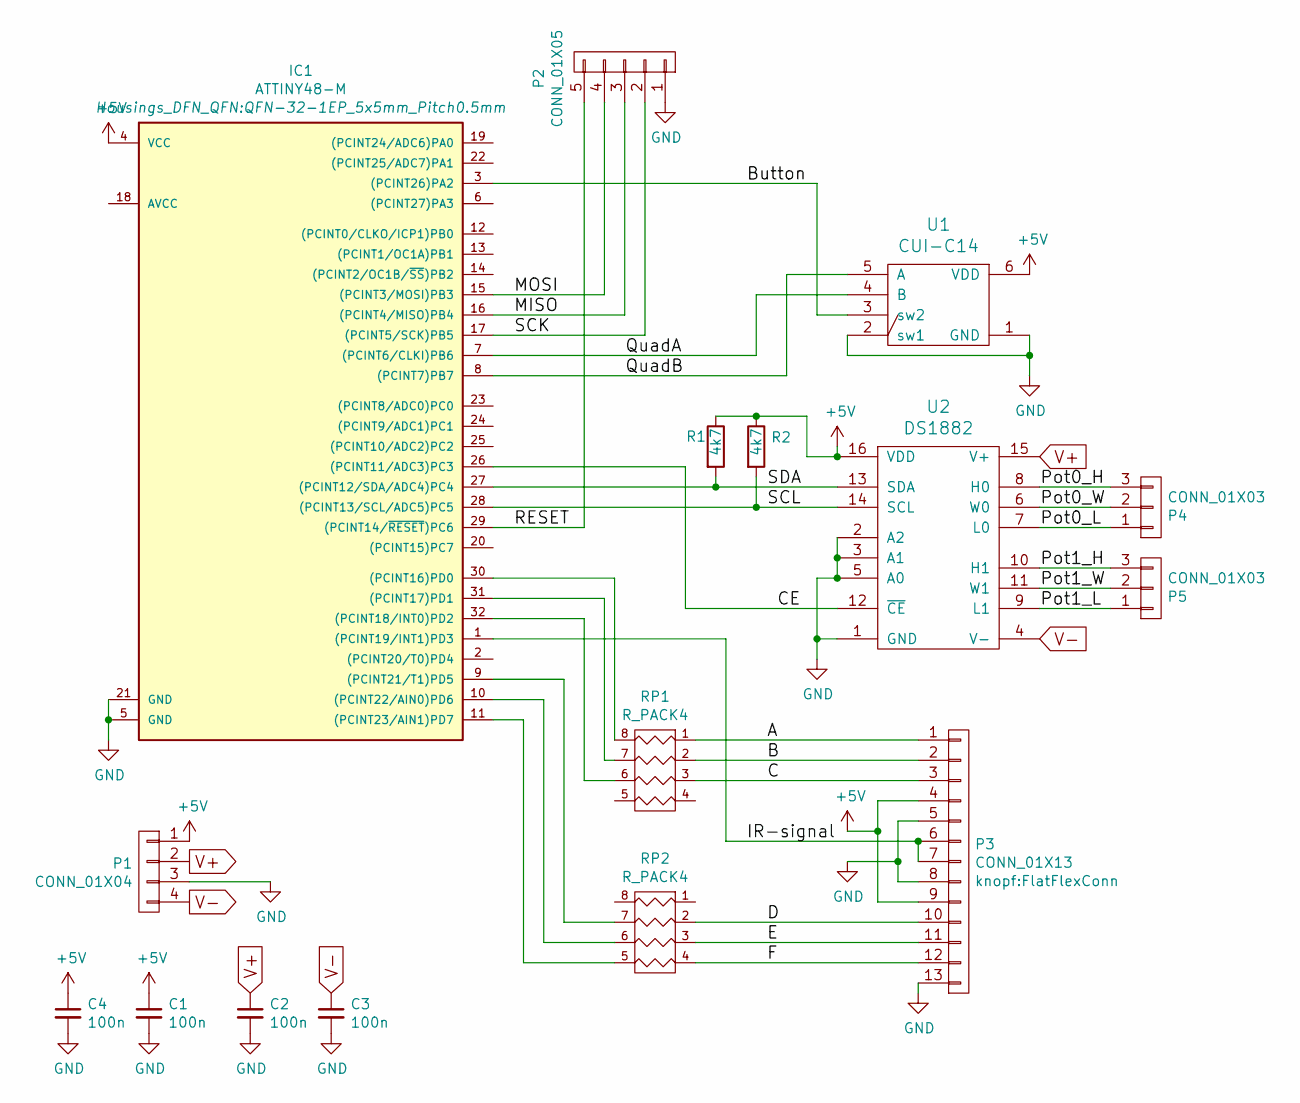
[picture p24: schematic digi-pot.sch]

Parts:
C1, C2, C3, C4: 100n; R_0603
IC1: ATTINY48-M; QFN-32-1EP_5x5mm_Pitch0.5mm
P1: CONN_01X04; Pin_Header_Straight_1x04
P2: CONN_01X05; Pin_Header_Straight_1x05
P3: CONN_01X13; FlatFlexConn
P4, P5: CONN_01X03; Pin_Header_Straight_1x03
R1, R2: 4k7; R_0603
RP1, RP2: R_PACK4; R_Array_Convex_4x0603
U1: CUI-C14
U2: DS1882; TSSOP-16_4.4x5mm_Pitch0.65mm

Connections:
+5V: C1.1, C4.1, IC1.4 (VCC), P1.1, P3.4, P3.9, R1.1, R2.1, U1.6 (VDD), U2.16 (VDD)
/A: P3.1, RP1.1
/B: P3.2, RP1.2
/Button: IC1.3 ((PCINT26)PA2), U1.3 (sw2)
/C: P3.3, RP1.3
/CE: IC1.26 ((PCINT11/ADC3)PC3), U2.12 (~CE)
/D: P3.10, RP2.2
/E: P3.11, RP2.3
/F: P3.12, RP2.4
/IR-signal: IC1.1 ((PCINT19/INT1)PD3), P3.6, P3.7
/MISO: IC1.16 ((PCINT4/MISO)PB4), P2.3
/MOSI: IC1.15 ((PCINT3/MOSI)PB3), P2.4
/Pot0_H: P4.3, U2.8 (H0)
/Pot0_L: P4.1, U2.7 (L0)
/Pot0_W: P4.2, U2.6 (W0)
/Pot1_H: P5.3, U2.10 (H1)
/Pot1_L: P5.1, U2.9 (L1)
/Pot1_W: P5.2, U2.11 (W1)
/QuadA: IC1.7 ((PCINT6/CLKI)PB6), U1.4 (B)
/QuadB: IC1.8 ((PCINT7)PB7), U1.5 (A)
/RESET: IC1.29 ((PCINT14/~RESET~)PC6), P2.5
/SCK: IC1.17 ((PCINT5/SCK)PB5), P2.2
/SCL: IC1.28 ((PCINT13/SCL/ADC5)PC5), R2.2, U2.14 (SCL)
/SDA: IC1.27 ((PCINT12/SDA/ADC4)PC4), R1.2, U2.13 (SDA)
GND: C1.2, C2.2, C3.2, C4.2, IC1.5 (GND), IC1.21 (GND), P1.3, P2.1, P3.5, P3.8, P3.13, U1.1 (GND), U1.2 (sw1), U2.1 (GND), U2.2 (A2), U2.3 (A1), U2.5 (A0)
unnamed: IC1.9 ((PCINT21/T1)PD5), RP2.7 (R2)
unnamed: IC1.10 ((PCINT22/AIN0)PD6), RP2.6 (R3)
unnamed: IC1.11 ((PCINT23/AIN1)PD7), RP2.5 (R4)
unnamed: IC1.30 ((PCINT16)PD0), RP1.8 (R1)
unnamed: IC1.31 ((PCINT17)PD1), RP1.7 (R2)
unnamed: IC1.32 ((PCINT18/INT0)PD2), RP1.6 (R3)
V+: C2.1, P1.2, U2.15 (V+)
V-: C3.1, P1.4, U2.4 (V-)

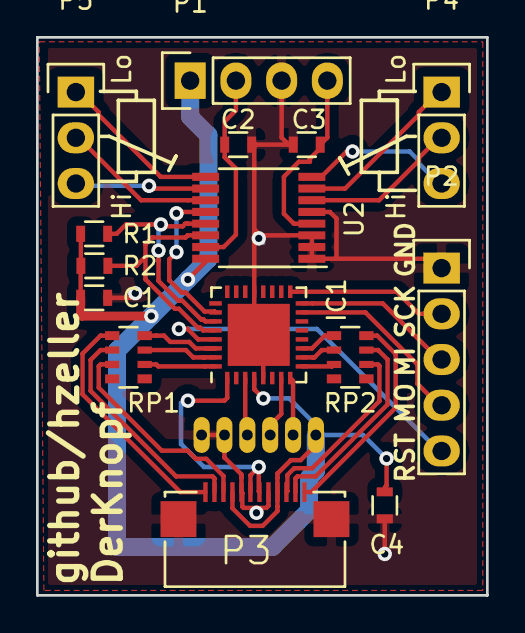
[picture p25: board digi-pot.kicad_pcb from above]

Board: 2 copper layers, 25.0 x 31.0 mm, 16 parts (1 on the bottom side), 33 nets.

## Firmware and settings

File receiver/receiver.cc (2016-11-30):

/* -*- mode: c++; c-basic-offset: 4; indent-tabs-mode: nil; -*-
 * Copyright (c) h.zeller@acm.org. GNU public License.
 *
 * Receiver for 'DerKnopf'.
 *   - Input something like TSOP38238 for infrared.
 *   - Also, we have a local rotational quadrature encoder.
 *   - Output digipot is a DS1882
 *   - A charlie-plexed LED ring shows the current pos.
 */

#define DO_SERIAL_COM 0

#include <stdint.h>
#include <avr/io.h>
#include <avr/interrupt.h>
#include <util/delay.h>
#include <avr/eeprom.h>

#include "quad.h"
#include "clock.h"
#include "i2c_master.h"

#if DO_SERIAL_COM
#  include "serial-com.h"
#else
typedef int SerialCom;  // dummy type.
// TODO: a version that sends via SPI
#endif

#define IR_PORT_IN  PIND
#define IR_PORT_OUT PORTD
#define IR_IN       (1<<3)

#define QUAD_PORT_IN  PINB
#define QUAD_PORT_OUT PORTB
#define QUAD_SHIFT    6
#define QUAD_IN       (3<<QUAD_SHIFT)

#define BUTTON_PORT_IN  PINA
#define BUTTON_PORT_OUT PORTA
#define BUTTON_IN       (1<<2)

#define DIGIPOT_READ  0x51
#define DIGIPOT_WRITE 0x50

// If histogram shift is defined, we spit out a histogram. And it only makes
// sense if we do serial.
#if DO_SERIAL_COM
#  define HISTOGRAM_SHIFT 3
#endif

static inline uint8_t quad_in() {
    // Flipping one bit as we get the signal in the wrong sequence.
    return ((QUAD_PORT_IN & QUAD_IN) >> QUAD_SHIFT) ^ 0b01;
}
static inline bool infrared_in() { return (IR_PORT_IN & IR_IN) != 0; }
static inline bool button_in() { return (BUTTON_PORT_IN & BUTTON_IN) == 0; }

struct EepromLayout {
    // The first character sometimes seems to be wiped out in power-glitch
    // situations; so let's not store anything of interest here.
    uint8_t dummy;

    uint8_t value;
    uint8_t is_muted;
};

// EEPROM layout with some defaults in case we'd want to prepare eeprom flash.
struct EepromLayout EEMEM ee_data = { 0, 0, 0 };

#if DO_SERIAL_COM
static uint8_t histogram[255];
static char to_hex(unsigned char c) { return c < 0x0a ? c + '0' : c + 'a' - 10; }
static void printHexByte(SerialCom *out, unsigned char c) {
    out->write(to_hex((c >> 4) & 0xf));
    out->write(to_hex((c >> 0) & 0xf));

}
static void PrintString(SerialCom *out, const char *str) {
    while (*str)
        out->write(*str++);
}
#endif

// (lifted from my other project, rc-screen)
static uint8_t read_infrared(uint8_t *buffer, SerialCom *com) {
    // The infrared input is default high.
    // A transmission starts with a long low phase (which triggered us to
    // be in this routine in the first place), followed by a sequence of bits
    // that are encoded in the duration of the high-phases. We interpret that as
    // long == 1, short == 0. The end of the signal is reached once we see the
    // high phase to be overly long (or: when 4 bytes are read).
    // The timings were determined empirically.
    uint8_t read = 0;
    uint8_t current_bit = 0x80;
    *buffer = 0;

    // manual measurment.
    //const unsigned short lo_hi_bit_threshold = 0x01CE;
    const unsigned short lo_hi_bit_threshold = 0x0318;
    const unsigned short end_of_signal = 10 * lo_hi_bit_threshold;
    unsigned short count = 0;

#ifdef HISTOGRAM_SHIFT
    const uint8_t* print_buffer = buffer;
    uint8_t divider = lo_hi_bit_threshold >> HISTOGRAM_SHIFT;
#endif

    while (read < 4) {
        while (!infrared_in()) {}  // skip low phase, wait for high.
        for (count = 0; infrared_in() && count < end_of_signal; ++count)
            ;
        if (count >= end_of_signal)
            break; // we're done - final high state.
        if (count > lo_hi_bit_threshold) {
            *buffer |= current_bit;
        }

#ifdef HISTOGRAM_SHIFT
        count >>= HISTOGRAM_SHIFT;
        if (count > 255) count = 255;
        histogram[count]++;
#endif

        current_bit >>= 1;
        if (!current_bit) {
            current_bit = 0x80;
            ++read;
            if (read == 4)
                break;
            ++buffer;
            *buffer = 0;
        }
    }
#ifdef HISTOGRAM_SHIFT
    PrintString(com, "hist: [");
    for (int i = 0; i < 255; ++i) {
        if (i == divider) {
            com->write('|');
        }
        if (histogram[i]) {
            printHexByte(com, i);
            com->write(':');
            printHexByte(com, histogram[i]);
            com->write(' ');
        }
    }
    PrintString(com, "]");
    printHexByte(com, print_buffer[0]);
    printHexByte(com, print_buffer[1]);
    printHexByte(com, print_buffer[2]);
    printHexByte(com, print_buffer[3]);
    PrintString(com, "\r\n");
#endif
    return read;
}

class DebouncedButton {
public:
    DebouncedButton() : is_on_(false), debounce_count_(0) {}

    bool DetectEdge(bool input) {
        if (!input) {
            is_on_ = false;
            debounce_count_ = 0;
            return false;
        }
        else if (is_on_) {
            return false;
        }
        else if (++debounce_count_ < 100) {
            return false;
        }
        is_on_ = true;
        debounce_count_ = 0;
        return true;
    }

private:
    bool is_on_;
    uint16_t debounce_count_;
};

struct CharlieLookup {
    uint8_t row;
    uint8_t col;
};
CharlieLookup ledData[30];

void InitLedData() {
    for (int i = 0; i < 30; ++i) {
        uint8_t row = i / 5;
        uint8_t col = i % 5;
        if (col >= row) col += 1;

#if 1
        // If cables rotated.
        row = 5 - row;
        col = 5 - col;
#endif

        if (row > 2) row += 2;
        if (col > 2) col += 2;
        ledData[i].row = row;
        ledData[i].col = col;
    }
}

void led_output(uint8_t value, bool on) {
    CharlieLookup &data = ledData[value];
    DDRD = (1 << data.row) | (1 << data.col);
    PORTD = ((on ? 1 : 0) << data.row);
}

void ds1882_init() {
    if (i2c_start(DIGIPOT_WRITE) == 0) {
        i2c_write(0x86);  // set to 63 step mode.
        i2c_stop();
    }
}

uint8_t value_mapping[30] = {
    0,  1, 2, 3, 4, 5,   // 1 step.
    7,  9, 11, 13, 15, 17, 19, 21, 23, 25, 27, 31, 33, 35, 37, 39,  // 2 step.
    42, 45, 48, 51, 54, 57, 60, 63  // 3 step.
};
void ds1882_set_pot_value(uint8_t value, bool muted) {
    if (muted) value = 0;

    // Value can be 0..29. The DS1882 has a range 0..63 with the
    // highest value being the most attenuation.
    uint8_t wiper = 63 - value_mapping[value];

    if (i2c_start(DIGIPOT_WRITE) == 0) {
        i2c_write((0 << 6) | wiper);
        i2c_write((1 << 6) | wiper);
        i2c_stop();
    }
}

inline static uint8_t GetEEValue(uint8_t* which) { return eeprom_read_byte(which); }
inline static uint8_t SetEEValue(uint8_t* which, uint8_t value) {
  eeprom_write_byte(which, value);
  return value;
}

int main() {
    InitLedData();
    Clock::init();
    i2c_init();
    ds1882_init();

    // Set pullups.
    IR_PORT_OUT |= IR_IN;
    BUTTON_PORT_OUT |= BUTTON_IN;
    QUAD_PORT_OUT |= QUAD_IN;

    SerialCom com;
    QuadDecoder knob(quad_in());
    DebouncedButton button;
    uint8_t buffer[4];

    // Set initial values we have kept in EEPROM
    int16_t pot_pos = GetEEValue(&ee_data.value);
    bool muted = GetEEValue(&ee_data.is_muted);

    // Default EEPROM value is 0xff the first time we power up. Make sure
    // we're in range.
    if (pot_pos < 0 || pot_pos > 29)
        pot_pos = 0;

    ds1882_set_pot_value(pot_pos, muted);

    bool change_needs_writing = false;
    Clock::cycle_t change_needs_writing_start;

    // The optical encoder needs some settle-time it seems. Discard changes
    // until we see 100ms of no change.
    Clock::cycle_t last_encoder_change = Clock::now();
    while (Clock::now() - last_encoder_change < Clock::ms_to_cycles(100)) {
        if (knob.UpdateEnoderState(quad_in()) != 0)
            last_encoder_change = Clock::now();
    }

    for (;;) {
        int16_t old_pos = pot_pos;

        if (button.DetectEdge(button_in())) {
            muted = !muted;
            old_pos = -1;  // force redraw
        }

        if (!infrared_in() && read_infrared(buffer, &com) == 4) {
            // Our sender.
            if (buffer[0] == 'm' && buffer[1] == 'o' && buffer[2] == 'r' && buffer[3] == 'e') {
                ++pot_pos;
            }
            else if (buffer[0] == 'l' && buffer[1] == 'e' && buffer[2] == 's' && buffer[3] == 's') {
                --pot_pos;
            }
            else if (buffer[0] == 'b' && buffer[1] == '_' && buffer[2] == 'o' && buffer[3] == 'n') {
                muted = !muted;
                old_pos = -1;
            }
        }

#if DO_SERIAL_COM && defined(HISTOGRAM_SHIFT)
        for (int i = 0; i < 255; ++i) histogram[i] = 0;
#endif

        pot_pos += knob.UpdateEnoderState(quad_in());

        if (pot_pos < 0) pot_pos = 0;
        if (pot_pos > 29) pot_pos = 29;

        if (old_pos != pot_pos) {
            ds1882_set_pot_value(pot_pos, muted);
#if DO_SERIAL_COM
            com.write((pot_pos / 10) + '0');
            com.write((pot_pos % 10) + '0');
            if (muted) { com.write(' '); com.write('M'); }
            com.write(' ');
            com.write('\r');
            com.write('\n');
#endif
            change_needs_writing = true;
            change_needs_writing_start = Clock::now();
        }

        bool is_on = !muted || ((Clock::now() & 0x1FFF) < 0xFFF);
        led_output(pot_pos, is_on);

        // Write current setting to eeprom, but only after it has been settled
        // for a while not to wear out the eeprom.
        if (change_needs_writing &&
            (Clock::now() - change_needs_writing_start > Clock::ms_to_cycles(1000))) {
            SetEEValue(&ee_data.value, pot_pos);
            SetEEValue(&ee_data.is_muted, muted);
#if DO_SERIAL_COM
            com.write('w');
            com.write('\r');
            com.write('\n');
#endif
            change_needs_writing = false;
        }
    }
}

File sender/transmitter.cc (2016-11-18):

/* -*- mode: c++; c-basic-offset: 4; indent-tabs-mode: nil; -*-
 * Copyright (c) h.zeller@acm.org. GNU public License.
 *
 * Transmitter for 'DerKnopf'
 *   - react on interrupt, waking up when reading the encoder
 *   - send stuff via infrared, 38kHz encoded.
 *   - Infrared receivers like a particular burst width, so we encode the bits
 *     in the spacing.
 *     (this gives a variable length encoding, but we don't care).
 */

#include <avr/io.h>
#include <avr/interrupt.h>
#include <avr/sleep.h>
#include <avr/power.h>

#include "quad.h"

// Do direct pullup for the quad encoder. However, these are relatively low
// values in the AVR, so if this is set to 0, then we use higher value 1MOhm
// pullups on the board.
#define ROT_DIRECT_PULLUP 1

// After we transmitted go back to power-off sleep until someone wakes us with
// a level change (button press or rotation). We only use 0.1 Microampere while
// in that mode.
#define SLEEP_AFTER_TRANSMIT 1

// We need to fudge up the frequency a bit because the RC oscillator runs
// a little slower at 3V.
#define IR_FREQ         (38000 * 1.0387)  // Frequency of IR carrier

// Need double transmit frequency for one cycle
#define CLOCK_COUNTER   F_CPU / (2.0 * IR_FREQ)

#define IR_OUT_PORT      PORTA
#define IR_OUT_DATADIR   DDRA
#define IR_OUT_BIT       (1<<0)
#define IR_DEBUG_BIT     (1<<1)    // Nice to trigger the scope on.
#define IR_BURST_LEN     (2 * 22)  // 22 cycles. two edges.
#define IR_INITIAL_BURST (4 * IR_BURST_LEN)
#define IR_BIT_0_PAUSE    28
#define IR_BIT_1_PAUSE   105
#define IR_FINAL_PAUSE   255

#define ROT_PORT_OUT PORTA
#define ROT_PORT_IN  PINA
#define ROT_A        (1<<7)   // Also PCINT
#define ROT_B        (1<<3)   // Also PCINT
#define ROT_PULLUP_A (1<<5)
#define ROT_PULLUP_B (1<<6)
#define ROT_INTR1     PCINT7
#define ROT_INTR2     PCINT3

#define BUT_PORT_IN   PINB
#define BUT_PORT_OUT  PORTB
#define BUT_BIT       (1<<0)   // Also PCINT to wakeup
#define BUT_INTR      PCINT8

// The commands we send are just a 32 bit values. Make that some text :)
#define MK_COMMAND(a, b, c, d) \
        ((uint32_t)a << 24 | (uint32_t)b << 16 | (uint32_t)c << 8 | d)
#define COMMAND_MORE MK_COMMAND('m', 'o', 'r', 'e')  // Knob turned right
#define COMMAND_LESS MK_COMMAND('l', 'e', 's', 's')  // Knob turned left
#define COMMAND_B_ON MK_COMMAND('b', '_', 'o', 'n')  // Button pressed
#define COMMAND_BOFF MK_COMMAND('b', 'o', 'f', 'f')  // Button released
#define COMMAND_BHLD MK_COMMAND('b', 'h', 'l', 'd')  // Button kept pressing

// Sending. All happens in an interrupt set up to fire in 2*38kHz
enum SendState {
    BIT_BURST,   // the burst at the beginning of a bit (longer initially)
    BIT_PAUSE,   // the pause, whose length the bit encodes.
    FINAL_PAUSE, // time between data segments
    SENDER_IDLE,
};
// State used in the ISR. To save time and space, we assign these to global
// registers.
register enum SendState send_state asm("r13");
register uint8_t countdown asm("r12");

static uint32_t data_to_send;
static uint32_t current_bit;

// Send a 32Bit value.
// "value" is the 32 bit value to send, typically just letters for easier
// debugging :)
void Send(uint32_t value) {
    data_to_send = value;
    current_bit = 0x80000000;
    send_state = BIT_BURST;
    countdown = IR_INITIAL_BURST;
    OCR0A = CLOCK_COUNTER;
    IR_OUT_PORT |= IR_DEBUG_BIT;
    TCNT0 = 0;
    TCCR0A = (1<<WGM01);   // OCRA compare. p.83
    TIMSK0 |= (1<<OCIE0A);  // Go
}

void advanceStateBottomHalf();

// Check if sending is done. Needs to be called regularly after a Send()
// has been issued.
bool PollIsSendingDone() {
    if (send_state == SENDER_IDLE)
        return true;
    if (countdown == 0)
        advanceStateBottomHalf();
    return false;
}

void advanceStateBottomHalf() {
    // Note, we need to set the state _before_ setting the countdown.
    // The interrupt is still running and polling send_state - so this results
    // in race-conditions.
    if (send_state == FINAL_PAUSE) {
        TIMSK0 &= ~(1<<OCIE0A);       // Disable interrupt. We are done.
        IR_OUT_PORT &= ~(IR_DEBUG_BIT|IR_OUT_BIT);
        send_state = SENDER_IDLE;  // External observers might be interested.
    }
    else if (send_state == BIT_BURST) {  // Just sent burst, now encode data
        if (current_bit == 0) {
            send_state = FINAL_PAUSE;
            IR_OUT_PORT &= ~(IR_OUT_BIT|IR_DEBUG_BIT);
            countdown = IR_FINAL_PAUSE;   // Ran out of data. Final pause.
        } else {
            send_state = BIT_PAUSE;
            IR_OUT_PORT &= ~(IR_OUT_BIT);
            // Data is encoded in the pause between the bursts.
            countdown = (current_bit & data_to_send)
                ? IR_BIT_1_PAUSE
                : IR_BIT_0_PAUSE;
        }
    }
    else {
        send_state = BIT_BURST;
        countdown = IR_BURST_LEN;
        current_bit >>= 1;
    }
}

ISR(TIM0_COMPA_vect) {
    if (countdown == 0)
        return;
    if (send_state == BIT_BURST) {
        IR_OUT_PORT ^= IR_OUT_BIT;
    } // else we're in a pause-phase.
    --countdown;
}

// Pin change interrupt. Dummy in the interrupt vector to wake up.
EMPTY_INTERRUPT(PCINT0_vect);
EMPTY_INTERRUPT(PCINT1_vect);

static bool is_button_pressed() { return (BUT_PORT_IN & BUT_BIT) == 0; }
static inline uint8_t rot_status() {
    const uint8_t rot_in = ROT_PORT_IN;
    return ((rot_in & ROT_B) ? 10 : 00) | ((rot_in & ROT_A) ? 01 : 00);
}
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

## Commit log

2015-03-09 o Fix race-condition as bottom-half operation might not be called timely (in particular a 4MHz).
    [transmitter.cc]
2015-03-09 o Rotate stepper on reciept of "more" or "less"
2015-03-13 o doh, the rotary encoder that will be used has only 12 detents.
    [case.scad, knob.scad]
2015-03-14 o Add bottom cut.
    [case.scad, knob.scad]
2015-03-14 o Move case to sub-dir
    [case.scad, knob.scad]
2015-03-14 o Mounting of the bottom to the case. o better modelling of LEDs. o Don't recess mounting hole for top of case for flat printing surface.
    [case.scad]
2015-03-14 o testing with more prominent knurls o Battery blades accessible for mounting. o battery text visible from below.
    [case.scad, knob.scad]
2015-03-14 o Make text not quite as embossed.
    [case.scad]
2015-03-15 o Smaller interrupt handler for waking up.
2015-03-19 o case tweaks.
    [case.scad]
2016-10-08 o Start LED-ring PCB
    [led-ring.kicad_pcb, led-ring.sch]
2016-10-09 o Add flat-flex footprint.
    [led-ring.kicad_pcb, led-ring.sch]
2016-10-09 o seed net-starts.
    [led-ring.kicad_pcb]
2016-10-09 o Get polygons started. Wired up first couple of LEDs.
    [led-ring.kicad_pcb]
2016-10-09 o Wire up LEDs.
    [led-ring.kicad_pcb]
2016-10-09 o make circle traces thicker.
    [led-ring.kicad_pcb]
2016-10-09 o Move outer rings to top layer to avoid a couple of vias.
    [led-ring.kicad_pcb]
2016-10-09 o Remove tail-traces - traces after the last via that uses them.
    [led-ring.kicad_pcb]
2016-10-09 o Fix accidentally set aux origin - that makes oshpark unhappy.
    [led-ring.kicad_pcb]
2016-10-09 o Add IR receiver. o Shape ring in a way so that receiver fits.
    [led-ring.kicad_pcb, led-ring.sch]
2016-10-09 o Make sure to only include the git version of the PCB.
2016-10-23 o add CUI footprint.
2016-10-23 o add base for digi pot
    [digi-pot.sch]
2016-10-23 o first schematic
    [digi-pot.sch]
2016-10-24 o complete schematic
    [digi-pot.sch]
2016-10-24 o First version PCB
    [digi-pot.kicad_pcb]
2016-10-24 o Make sure gitversion string fits on board.
    [digi-pot.kicad_pcb]
2016-10-24 o Better marking of input voltages.
    [digi-pot.kicad_pcb]
2016-11-01 o Add little power supply breakout; one-sided for simple hand-etching.
    [power-supply.kicad_pcb, power-supply.sch]
2016-11-01 o Add marking.
    [power-supply.kicad_pcb]
2016-11-06 o read local quadrature encoder. o output current pos to charlie-plexed LED ring. o Remove motor output.
2016-11-07 o Add pull-ups for I2C bus. o smallish changes in power supply.
    [digi-pot.kicad_pcb, digi-pot.sch, power-supply.kicad_pcb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]
2016-11-07 o store last state in eeprom. o discard early reads of encoder to not create a false reading right after reset.
    [i2c_master.c, quad.cc, receiver.cc]
2016-11-12 o first version remote control.
    [power-supply.kicad_pcb, remote-control.kicad_pcb, remote-control.sch]
2016-11-12 o Make IR engergy storage 1206 SMD size o add 0603 package for 100n bypass.
    [remote-control.kicad_pcb, remote-control.sch]
2016-11-15 o Make transmitter work with new PCB.
2016-11-15 o Receive button press and connect to mute.
2016-11-15 o add histogram for determining best cut-off between 0 and 1 bit.
2016-11-18 o interrupt actually did work, just wrong lines selected.
    [transmitter.cc]
2016-11-19 o update Readme with the new direction of project (previously: controlling stepper motor, now DS1882).
2016-11-19 o Change from development set-up (Atmega8) to production set-up (Attiny48): no UART serial connection anymore. different IO-pins.
2016-11-19 o Add serial communication code for set-ups that have UART
2016-11-19 o add forgotten footprint: FlatFlex connector
2016-11-19 o connect flat flex connector ground to ground.
    [digi-pot.kicad_pcb, digi-pot.sch]
2016-11-19 o Initialize fuses for Attiny48 o Honor different pinout of LEDs in PCB. o Don't initialize histogram if we're not using it.
2016-11-20 o light up led-ring picture.
2016-11-20 o Flipped A/B in production board.
    [receiver.cc]
2016-11-20 o simplify initialization of quad decoder. o Initialization: wait until rotational encoder has settled.
2016-11-20 o Remove a couple of non-useful 3D component renderings
    [power-supply.kicad_pcb, remote-control.kicad_pcb]
2016-11-20 o Add some basic READMEs for the PCB directories.
    [remote-control.sch]
2016-11-20 o add a couple more cross-links between readmes
2016-11-20 o Add BOM for remote control sender. o Add battery considerations and possible future revision changes.
2016-11-21 o Update remote control: ready for a larger battery and housing o start housing.
    [remote-control.kicad_pcb, remote-control.sch, remote.dxf]
2016-11-21 o larger screw holes.
    [remote.dxf]
2016-11-21 o smaller set.
    [remote.dxf]
2016-11-21 o large hole
    [remote.dxf]
2024-02-14 led-ring: Update to Kicad 7
    * Use new schematic symbols and footprints
    * adjust board configuration for good solder stop expansion
    * Update Python script to work with current kicad.
    [led-ring.kicad_pcb, led-ring.kicad_sch, led-ring.sch]
2024-02-14 Update gitignore to match current filenames.
2024-02-14 Rotate LED designators to read horizontally.
    [led-ring.kicad_sch]
2024-02-14 Move designators out of view.
    The LED numbering is not really helping while populating, but
    clutters the look of the ring that we want to keep focused on the
    LEDs.
    [led-ring.kicad_pcb]
